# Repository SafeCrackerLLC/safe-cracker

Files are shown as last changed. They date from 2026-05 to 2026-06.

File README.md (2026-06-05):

# Safe Cracker

> Interaktivna ESP32 igra otključavanja sefa s OLED prikazom, fizičkim kontrolama i WiFi leaderboardom.

# Opis projekta

Ovaj projekt je rezultat timskog rada u sklopu projektnog zadatka kolegija **Razvoj ugradbenih sustava** na **Tehničkom veleučilištu u Zagrebu**.

**Safe Cracker** je interaktivna igra otključavanja sefa izrađena pomoću ESP32 mikrokontrolera, OLED zaslona i fizičkih kontrola. Igrač mora precizno okretati bravu sefa kako bi pogodio zadane ciljeve i otključao sef.

Cilj projekta bio je izraditi funkcionalan ugradbeni sustav koji povezuje hardver, softver, korisničko sučelje i bežičnu komunikaciju. Projekt uključuje prikaz igre na OLED zaslonu, upravljanje pomoću fizičkih kontrola, zvučni feedback, mjerenje vremena, izračun rezultata te slanje rezultata na web leaderboard.

Motivacija projekta bila je izraditi zabavan uređaj koji prikazuje primjenu ESP32 mikrokontrolera u interaktivnoj igri. Projekt simulira okretanje brave sefa, pri čemu se puhanje i udisanje u prototipu mogu simulirati potenciometrom.

# Funkcijski zahtjevi

> Ključni zahtjevi projekta su:

* prikaz igre na OLED zaslonu
* upravljanje igrom pomoću fizičkih kontrola
* simulacija otključavanja sefa
* simulacija puhanja i udisanja pomoću potenciometra
* izbor razine težine
* mjerenje vremena rješavanja
* izračun i prikaz rezultata
* zvučni feedback pomoću pasivne zujalice
* WiFi konfiguracija uređaja
* slanje rezultata na web servis
* prikaz rezultata na web leaderboardu
* mogućnost rada u online i offline načinu rada
* lokalno generiranje dokumentacije pomoću Doxygena
* automatsko objavljivanje dokumentacije pomoću GitHub Actions i GitHub Pages

# Tehnologije

* ESP32
* Arduino/C++
* OLED zaslon
* I2C komunikacija
* potenciometar
* joystick
* tipka
* pasivna zujalica
* WiFi
* Python
* Flask
* SQLite
* HTML
* CSS
* JavaScript
* Doxygen
* GitHub Actions
* GitHub Pages

# Instalacija

Kloniranje repozitorija:

```bash
git clone https://github.com/SafeCrackerLLC/safe-cracker.git
cd safe-cracker
```

Za rad s ESP32 dijelom projekta potrebno je imati instalirano Arduino razvojno okruženje ili drugo kompatibilno okruženje za razvoj ESP32 aplikacija.

Python webhook i leaderboard nalaze se u direktoriju `webpage/`.

Pokretanje web servisa:

```bash
podman compose -f webpage/compose.yaml up -d --build
```

Doxygen dokumentacija može se generirati lokalno naredbom:

```bash
doxygen Doxyfile
```

HTML dokumentacija generira se u:

```text
docs/html/index.html
```

GitHub Actions workflow `.github/workflows/doxygen.yml` generira dokumentaciju na `main` grani i objavljuje je preko GitHub Pages.

# Članovi tima

> Popis članova tima, linkovi i glavni doprinos.

| Član tima | Glavni doprinos |
| --- | --- |
| Luka Šarić | ESP32 logika igre |
| David Gulić | Web leaderboard i backend |
| Leo Znika | Dokumentacija, testiranje i kućište |

# Kontribucije

> Pravila ovise o organizaciji tima i često su izdvojena u `CONTRIBUTING.md`.

Pravila za doprinos projektu definirana su u dokumentu [`CONTRIBUTING.md`](CONTRIBUTING.md).

Članovi tima dogovorili su podjelu rada prema funkcionalnim cjelinama projekta. Komunikacija se odvija putem dogovorenih kanala tima, a promjene se prate kroz GitHub repozitorij.

Prilikom rada na projektu očekuje se:

* poštivanje dogovorene strukture projekta
* pisanje razumljivog i održivog koda
* dokumentiranje važnih dijelova sustava
* korištenje GitHub pull requestova ili dogovorenog načina spajanja promjena
* međusobno poštovanje članova tima
* poštivanje kodeksa ponašanja

# 📝 Kodeks ponašanja 

Kao studenti upoznati smo s minimumom prihvatljivog ponašanja definiranim u kodeksu ponašanja studenata.

Očekujemo poštivanje [etičkog kodeksa IEEE-a](https://www.ieee.org/about/corporate/governance/p7-8.html), koji ima važnu obrazovnu funkciju postavljanja visokih standarda integriteta, odgovornog ponašanja i etičkog djelovanja u profesionalnim aktivnostima.

Kodeks ponašanja skup je provedivih pravila koja služe za jasnu komunikaciju očekivanja i zahtjeva za rad zajednice ili tima. Njime se definiraju obaveze, prava, neprihvatljiva ponašanja te odgovarajuće posljedice.

U ovom repozitoriju koristi se jedan od široko prihvaćenih kodeksa ponašanja za rad u zajednici otvorenog koda: [`Contributor Covenant`](CODE_OF_CONDUCT.md).

> ### Poboljšanje funkcioniranja tima:
>
> * definirati način na koji će rad biti podijeljen među članovima grupe
> * dogovoriti kako će grupa međusobno komunicirati
> * ne gubiti vrijeme na dogovore o rješavanju sporova, već primijeniti postojeće standarde
> * podrazumijeva se da će svi članovi grupe slijediti kodeks ponašanja

Neprihvatljivo ponašanje može se prijaviti održavateljima projekta putem kontakt adrese navedene u dokumentu [`CODE_OF_CONDUCT.md`](CODE_OF_CONDUCT.md).

# 📝 Licenca

Ovaj projekt licenciran je pod **GNU General Public License v3.0** licencom.

GNU GPL v3.0 omogućuje korištenje, proučavanje, mijenjanje i dijeljenje programskog koda, uz uvjet da se izvedene verzije distribuiraju pod istim licencnim uvjetima.

Detalji licence nalaze se u datoteci [`LICENSE`](LICENSE).

> ### Napomena:
>
> Svi paketi, biblioteke i vanjski alati korišteni u projektu distribuiraju se pod vlastitim licencama.
> Svi upotrijebljeni materijali, uključujući slike, modele, animacije i druge resurse, distribuiraju se pod vlastitim licencama.
>
> Originalni predložak README dokumenta korišten u sklopu kolegija licenciran je pod CC0 1.0 Universal licencom.

Originalni predložak:

[][cc0-1.0]

> COPYING: All the content within the original template repository is dedicated to the public domain under the CC0 1.0 Universal Public Domain Dedication.

[][cc0-1.0]

# Reference na licenciranje repozitorija

* [GNU General Public License v3.0](https://www.gnu.org/licenses/gpl-3.0.en.html)
* [CC0 1.0 Universal](https://creativecommons.org/publicdomain/zero/1.0/deed.hr)

[cc0-1.0]: https://creativecommons.org/publicdomain/zero/1.0/deed.hr
[cc0-1.0-image]: https://licensebuttons.net/p/zero/1.0/88x31.png
[cc0-1.0-shield]: https://img.shields.io/badge/License-CC0--1.0-lightgrey.svg

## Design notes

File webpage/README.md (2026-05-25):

# SafeCracker Web

Python/Flask webhook and leaderboard for ESP32 scores.

## Run locally

```sh
python -m venv .venv
. .venv/bin/activate
pip install -r requirements.txt
python app.py
```

The app listens on `http://localhost:8000` when run directly.

## Run on server with Podman

```sh
podman compose -f webpage/compose.yaml up -d --build
```

Caddy can proxy Cloudflare traffic to:

```caddyfile
ruc-esp.nerizz.com {
  reverse_proxy 127.0.0.1:18080
}
```

The compose file maps host port `18080` to container port `8000`, so it will not conflict with another host service already using `8000`.

If Caddy also runs as a container in the same Podman network, remove the `ports` block and proxy directly to the service name:

```caddyfile
ruc-esp.nerizz.com {
  reverse_proxy safecracker-web:8000
}
```

ESP32 posts scores to:

```text
POST https://ruc-esp.nerizz.com/api/scores
```

`POST /` also accepts the same payload, so a device configured with only `https://ruc-esp.nerizz.com` will still upload scores.

Example payload:

```json
{
  "device_id": "SC-1234",
  "level": 1,
  "level_name": "Level 1",
  "time_ms": 18500,
  "stability": 92,
  "targets_hit": 5,
  "target_count": 5
}
```

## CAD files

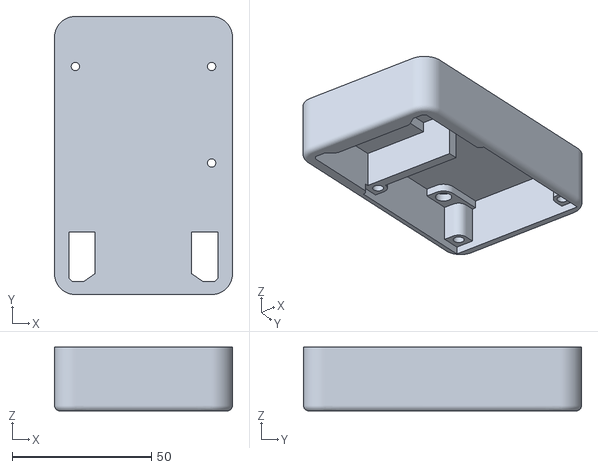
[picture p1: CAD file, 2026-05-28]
models/backMain.stl
64.0 x 100.0 x 23.0

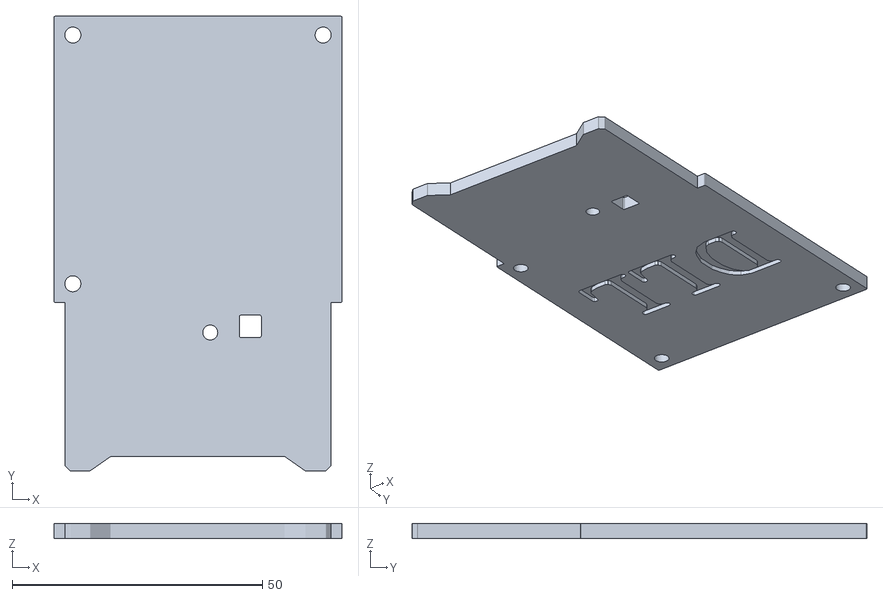
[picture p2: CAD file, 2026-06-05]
models/batteryCover.stl
57.5 x 90.8 x 3.00

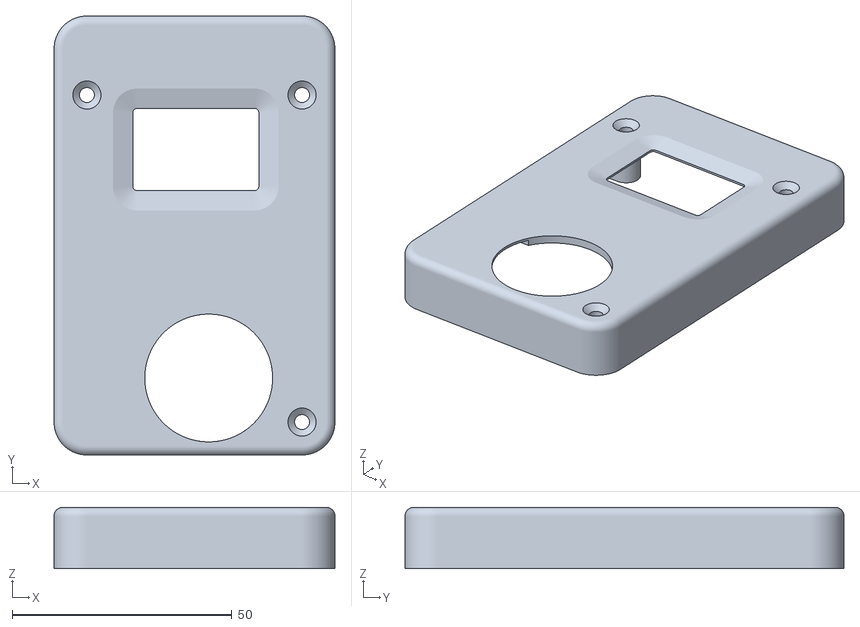
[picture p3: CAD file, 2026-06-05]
models/frontPlate.stl
64.0 x 100.0 x 14.0

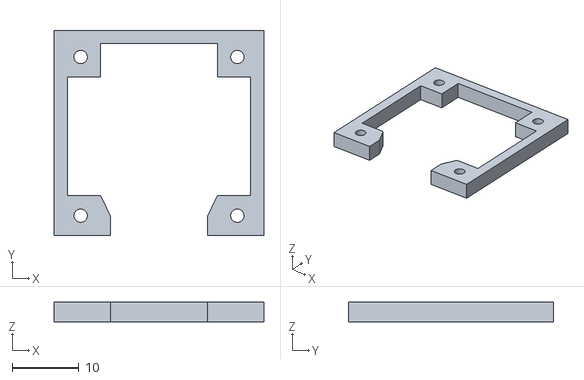
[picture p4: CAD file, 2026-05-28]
models/screenPlate.stl
31.5 x 30.8 x 3.00

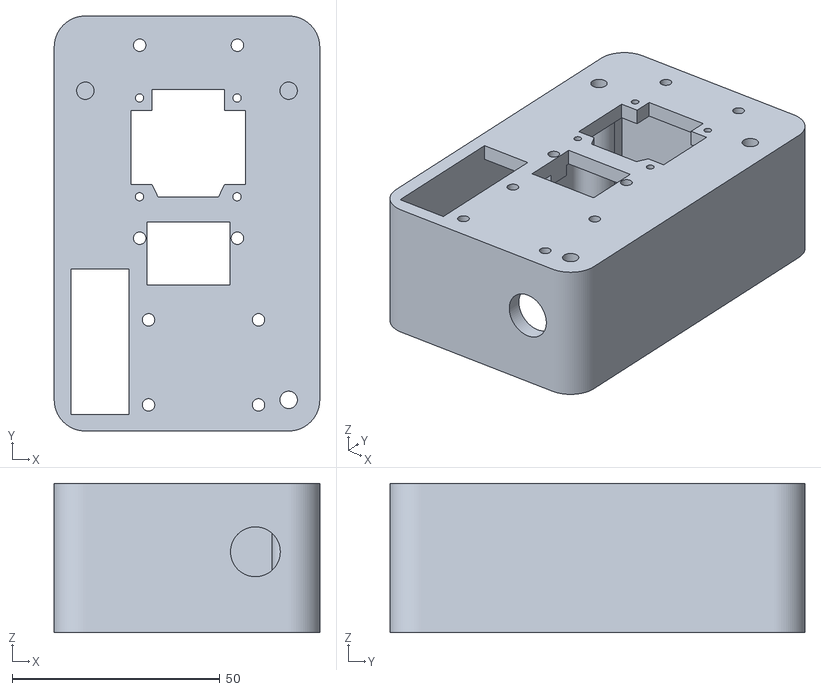
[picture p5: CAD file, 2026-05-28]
models/middle.stl
64.0 x 100.0 x 36.0

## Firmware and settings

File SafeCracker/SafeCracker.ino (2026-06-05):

#include <Wire.h>
#include <Adafruit_GFX.h>
#include <Adafruit_SSD1306.h>

/**
 * @file SafeCracker.ino
 * @brief Arduino entry point za SafeCracker firmware.
 *
 * Datoteka inicijalizira hardver, definira globalno stanje iz State.h i
 * pokrece glavnu petlju koja spaja mrezu, ulaze, logiku igre, prikaz i sleep.
 */

#include "Config.h"
#include "Feedback.h"
#include "GameLogic.h"
#include "Input.h"
#include "Level.h"
#include "SafeNetwork.h"
#include "Power.h"
#include "Rendering.h"
#include "State.h"

// --------------------
// Display setup
// --------------------
Adafruit_SSD1306 display(SCREEN_WIDTH, SCREEN_HEIGHT, &Wire, -1);

// --------------------
// Game state
// --------------------
float vaultAngle = 0;
float barFill = 0;
int lastValue = 0;
int currentTargetIndex = 0;
int selectedLevelIndex = 0;
int selectedNetworkInfoAction = 0;
int gameScreen = GAME_SCREEN_LEVEL_SELECT;
bool levelWasWon = false;
int joystickCenterValue = JOYSTICK_CENTER_VALUE;
bool joystickMenuReady = true;
unsigned long gameStartTime = 0;
unsigned long levelFinishedTime = 0;
unsigned long targetHitStartTime = 0;
unsigned long lastJoystickMoveTime = 0;
unsigned long levelSolvedTimeMs = 0;
int levelStabilityScore = 0;
int stabilitySampleCount = 0;
float stabilityErrorSum = 0;
int stabilityOvershootCount = 0;
int stabilityDirectionChanges = 0;
int lastPotDirection = 0;
int currentRunTargetCount = 0;
float currentRunTargets[MAX_LEVEL_TARGETS];
int targetStabilityScore[MAX_LEVEL_TARGETS];
int targetStabilitySampleCount[MAX_LEVEL_TARGETS];
float targetStabilityErrorSum[MAX_LEVEL_TARGETS];
int targetStabilityOvershootCount[MAX_LEVEL_TARGETS];
int targetStabilityDirectionChanges[MAX_LEVEL_TARGETS];
int targetLastPotDirection[MAX_LEVEL_TARGETS];
int replayEventCount = 0;
unsigned long replayEventTimeMs[MAX_REPLAY_EVENTS];
float replayEventFill[MAX_REPLAY_EVENTS];
int replayEventTargetIndex[MAX_REPLAY_EVENTS];
int replayEventType[MAX_REPLAY_EVENTS];
unsigned long lastReplayEventTime = 0;
float lastReplayEventFill = 0;
/** Zadnje vrijeme ispisa statusa na Serial monitor. */
unsigned long lastSerialStatusTime = 0;

// --------------------
// Device / power state
// --------------------
unsigned long lastActivityTime = 0;
volatile bool sleepRequested = false;
esp_timer_handle_t sleepTimer = NULL;
bool wifiConfigPortalActive = false;
bool wifiConnectInProgress = false;
bool wifiHasCredentials = false;
bool wifiOfflineMode = false;
unsigned long wifiConnectStartedAt = 0;
String configuredSsid = "";
String configuredPassword = "";
String configuredWebhookUrl = "";
String wifiPortalSsid = "";
String networkStatusMessage = "";

// --------------------
// Arduino setup
// --------------------
/**
 * @brief Inicijalizira pinove, OLED, ulazne uredjaje, sleep timer i mrezu.
 */
void setup() {
  pinMode(BUZZER_PIN, OUTPUT);
  pinMode(VIBRATION_PIN, OUTPUT);
  pinMode(JOYSTICK_Y_PIN, INPUT);
  pinMode(BUTTON_PIN, INPUT_PULLUP);
  digitalWrite(VIBRATION_PIN, LOW);

  Serial.begin(115200);
  delay(1000);
  Serial.println("SafeCracker booting...");
  Serial.println("Starting I2C on SDA 21 / SCL 22...");
  Wire.begin(OLED_SDA_PIN, OLED_SCL_PIN);

  Serial.println("Starting OLED...");
  if (!display.begin(SSD1306_SWITCHCAPVCC, 0x3C)) {
    Serial.println("OLED not found!");
    while (true);
  }
  Serial.println("OLED found.");

  display.ssd1306_command(SSD1306_SETCONTRAST);
  display.ssd1306_command(255);
  display.clearDisplay();
  display.setTextSize(1);
  display.setTextColor(WHITE);
  display.setCursor(0, 0);
  display.println("SafeCracker");
  display.println("OLED test OK");
  display.drawRect(0, 0, SCREEN_WIDTH, SCREEN_HEIGHT, WHITE);
  display.display();
  delay(2000);

  display.clearDisplay();
  display.display();

  Serial.println("Reading potentiometer...");
  lastValue = analogRead(POT_PIN);
  Serial.println("Calibrating joystick...");
  calibrateJoystickCenter();
  Serial.println("Starting sleep timer...");
  lastActivityTime = millis();
  initializeSleepTimer();
  Serial.println("Starting network...");
  initializeNetwork();
  Serial.println("SafeCracker ready.");
}

// --------------------
// Arduino game loop
// --------------------
/**
 * @brief Glavna Arduino petlja.
 *
 * Periodicki obradjuje WiFi, tipke/joystick, timer levela, potenciometar,
 * crtanje ekrana i ulazak u deep sleep.
 */
void loop() {
  updateNetwork();
  handleButtonActivity();

  if (millis() - lastSerialStatusTime >= 2000) {
    lastSerialStatusTime = millis();
    Serial.print("Running. Screen=");
    Serial.print(gameScreen);
    Serial.print(" WiFi=");
    Serial.println(getWifiStatusLabel());
  }

  if (gameScreen == GAME_SCREEN_PLAYING) {
    updateLevelTimer();
    updateVaultRotationFromPot();
  }

  drawGame();
  sleepIfInactive();

  delay(10);
}

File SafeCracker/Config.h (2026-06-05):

#ifndef CONFIG_H
#define CONFIG_H

/**
 * @file Config.h
 * @brief Centralne hardverske pin definicije i konstante igre.
 *
 * Vrijednosti u ovoj datoteci koriste svi moduli firmwarea: prikaz,
 * logika levela, mreza, ulazni uredjaji i upravljanje potrosnjom.
 */

// --------------------
// Hardware pins
// --------------------
/** GPIO pin pasivne zujalice. */
#define BUZZER_PIN 13
/** GPIO pin vibracijskog motora. */
#define VIBRATION_PIN 26
/** ADC pin potenciometra koji simulira okretanje brave. */
#define POT_PIN 34
/** Joystick Y mora koristiti ADC1 jer ADC2 nije pouzdan dok je WiFi aktivan. */
#define JOYSTICK_Y_PIN 33
/** GPIO pin tipke, konfiguriran kao INPUT_PULLUP. */
#define BUTTON_PIN 12
/** I2C SDA pin OLED ekrana. */
#define OLED_SDA_PIN 21
/** I2C SCL pin OLED ekrana. */
#define OLED_SCL_PIN 22

// --------------------
// Display setup
// --------------------
/** Sirina OLED ekrana u pikselima. */
#define SCREEN_WIDTH 128
/** Visina OLED ekrana u pikselima. */
#define SCREEN_HEIGHT 64

// --------------------
// Game settings
// --------------------
/** X koordinata sredista nacrtane brave. */
const int VAULT_CENTER_X = 58;
/** Y koordinata sredista nacrtane brave. */
const int VAULT_CENTER_Y = 42;
/** Vanjski radijus brave na OLED-u. */
const int VAULT_OUTER_RADIUS = 20;
/** Unutarnji radijus sredista brave. */
const int VAULT_INNER_RADIUS = 5;
/** Duljina jedne rucke/kazaljke brave. */
const int VAULT_HANDLE_LENGTH = 15;
/** Radijus kruzica na kraju rucke brave. */
const int VAULT_HANDLE_RADIUS = 3;
/** Broj rucki koje se crtaju na bravi. */
const int VAULT_HANDLE_COUNT = 3;
/** Jedan puni krug u radijanima. */
const float FULL_ROTATION = 6.2831853;
/** X koordinata lijevog ruba horizontalne trake okretanja. */
const int BAR_X = 8;
/** Y koordinata gornjeg ruba horizontalne trake okretanja. */
const int BAR_Y = 2;
/** Sirina horizontalne trake okretanja. */
const int BAR_WIDTH = 112;
/** Visina horizontalne trake okretanja. */
const int BAR_HEIGHT = 12;
/** X koordinata sredine trake okretanja. */
const int BAR_CENTER_X = BAR_X + BAR_WIDTH / 2;
/** Osnovna Y koordinata strelice trenutnog cilja. */
const int TARGET_ARROW_Y = BAR_Y + BAR_HEIGHT + 6;
/** Velicina trokuta strelice trenutnog cilja. */
const int TARGET_ARROW_SIZE = 4;
/** Y koordinata strelice dok animacijski dodiruje traku. */
const int TARGET_ARROW_TOUCH_Y = BAR_Y + BAR_HEIGHT + TARGET_ARROW_SIZE;
/** Trajanje jednog ciklusa animacije strelice u milisekundama. */
const int TARGET_ARROW_CYCLE_MS = 1800;
/** Trajanje faze u kojoj je strelica spustena do trake. */
const int TARGET_ARROW_HOLD_MS = 120;
/** X koordinata vertikalne trake napretka kroz level. */
const int PROGRESS_BAR_X = 0;
/** Y koordinata vertikalne trake napretka kroz level. */
const int PROGRESS_BAR_Y = 18;
/** Sirina vertikalne trake napretka kroz level. */
const int PROGRESS_BAR_WIDTH = 5;
/** Visina vertikalne trake napretka kroz level. */
const int PROGRESS_BAR_HEIGHT = 44;
/** X koordinata teksta timera. */
const int TIMER_X = 9;
/** X koordinata poruke disanja. */
const int BREATH_TEXT_X = 91;
/** X koordinata okvira poruke disanja. */
const int BREATH_TEXT_BOX_X = 89;
/** Y koordinata okvira poruke disanja. */
const int BREATH_TEXT_BOX_Y = VAULT_CENTER_Y - 7;
/** Sirina okvira poruke disanja. */
const int BREATH_TEXT_BOX_WIDTH = 39;
/** Visina okvira poruke disanja. */
const int BREATH_TEXT_BOX_HEIGHT = 13;
/** Y koordinata kratke poruke za trenutni cilj. */
const int TARGET_MESSAGE_Y = BREATH_TEXT_BOX_Y + BREATH_TEXT_BOX_HEIGHT + 2;
/** Najmanja ADC vrijednost potenciometra. */
const int POT_MIN_VALUE = 0;
/** Najveca ADC vrijednost potenciometra. */
const int POT_MAX_VALUE = 4095;
/** Minimalna promjena ADC vrijednosti koja se smatra stvarnim okretanjem. */
const int POT_DEADZONE = 50;
/** Trajanje kratkog klik feedbacka u milisekundama. */
const int CLICK_VIBRATION_MS = 15;
/** Minimalno trajanje vibracijskog impulsa u milisekundama. */
const int MIN_VIBRATION_PULSE_MS = 60;
/** Najmanja ADC vrijednost joystick Y osi. */
const int JOYSTICK_MIN_VALUE = 0;
/** Najveca ADC vrijednost joystick Y osi. */
const int JOYSTICK_MAX_VALUE = 4095;
/** Zadana neutralna vrijednost joysticka prije kalibracije. */
const int JOYSTICK_CENTER_VALUE = 2048;
/** Broj uzoraka za kalibraciju neutralne vrijednosti joysticka. */
const int JOYSTICK_CENTER_SAMPLE_COUNT = 16;
/** Udaljenost od centra koju joystick mora prijeci za pomak menija. */
const int JOYSTICK_DEADZONE = 1000;
/** Minimalni razmak izmedju ponovljenih pomaka menija joystickom. */
const unsigned long JOYSTICK_MENU_REPEAT_MS = 250;
/** Faktor kojim se ADC promjena pretvara u kut rotacije brave. */
const float ROTATION_SPEED = 0.01;
/** Tolerancija unutar koje se cilj smatra pogodjenim. */
const float TARGET_HIT_TOLERANCE = 0.08;
/** Dopusteno prebacivanje preko cilja prije kazne za stabilnost. */
const float TARGET_OVERSHOOT_ALLOWANCE = 0.05;
/** Vrijeme koje igrac mora zadrzati cilj unutar tolerancije. */
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

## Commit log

2026-05-28 device files
    STL, STEP and F3Z files of device model
    [backMain.stl, batteryCover.stl, frontPlate.stl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]
2026-06-05 feat: reorganised models
    [backMain.stl, batteryCover.stl, frontPlate.stl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]
